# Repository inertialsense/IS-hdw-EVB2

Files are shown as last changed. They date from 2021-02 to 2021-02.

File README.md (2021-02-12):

# EVB-2 Evaluation Board

The Inertial Sense [EVB-2](https://docs.inertialsense.com/user-manual/hardware/EVB2/) is a development board which contains the Inertial Sense µINS, µAHRS, or µIMU module. The EVB-2 builds on the foundation established by the EVB-1, but adds these and other new features:

- 915MHz Xbee radio for RTK (real-time-kinematics)
- Wi-Fi and Bluetooth Low energy (BLE) for remote data viewing and logging operation
- Onboard logging to micro SD card.
- Dual antenna ports for GPS compassing
- Companion Microchip SAME70 processor that serves as a communication bridge between the µINS, µAHRS, or µIMU and all other interfaces.

The EVB-2 PCB assembly design files are provided in Altium Designer format.

------

## LICENSE



Use these Hardware Design files as you wish.  Inertial Sense is not liable for any claim, damages, or other liability resulting from their use.  See the included *LICENSE* file for details.

------

## Revision Info

### r2.1.2

+ Move TIOA1 (TC input) pin from GPIO1 to GPIO9 for measuring encoder velocity on to GPIO9 (multi-tie).  We would not like to have to tie GPIO9 and GPIO3 together offboard the EVB-2 for wheel encoder input.  We share the QDEC and TC input on the same line for angle and velocity measurement.

+ Consider adding a TC input to each of the QDEC channel A lines so all wheel encoder inputs support velocity measurement.
+ Add second CAN transceiver from EVB E70 to H2 and remove CAN jumper.  We can share H2 with uINS and EVB-E70.  Connect transceivers disable line to jumper or EVB disable line.
+ Enlarge fiducials from 0.76mm to 1.0mm on both sides.
+ Fix the I2C line (SDA, SCL) reversal on EVB-2 SAME70.

________________________________________________________________________________

### r2.1.0

+ Dual purpose reset line to reset uINS and MCU using an RC filters.  One resets
  quickly and the other follows after a delay.
+ Consider loading ICE debugger header for SAME70 MCU by default to support
  developers.
+ Expose uINS data ready pin GPIO13 on H7.
+ Fix top layer copper pour for XBee regulator input that connects C20 pin 2 to
  XBee regulator U7 pin 1.
+ Cut trace (disconnect) VUSB from ESD protection for both USB ports.  It's
  causing voltage to appear on FET switches and partially enable.
+ Add EVB version number to PCB
+ Consider switching battery to Seiko MS621T for -40 to 85 C temp range.
+ Add jumper selection of CAN transceiver to uINS and EVB processor for CAN
  support.
+ Consider exposing SAME70 chip erase (PB12) to SMT resistor pads to 3.3V.
+ Fix reversed uINS CAN Rx and Tx lines.  (Double check this).

________________________________________________________________________________

### r2.0.1

+ Add inverted bold labels for I/O headers.
+ Reverse the H1 power pin order so pin 1 is positive and pin 2 ground.
+ Add fiducials to help SMT machine alignment.
+ Invert and increase label size for I/O headers so they are easier to read.
+ Move to new button style
+ Fit shorter U.FL cables
+ Fix error that applied H1 voltage to the USB port in the power schematic
+ Remove or fix XBee USB power FET logic (Q3).
+ Remove R51 and connect with trace.
+ Fix RX line of XOR gate.
+ Add version label.
+ Update manufacturing docs for new U.FL cables (current cables are good)
+ Jumper to G1_SDA and G2_SCL to CAN transceiver to support future generation
  of uINS which will have new processor with CAN stack. 
+ Consider consolidating the power input FET arrays
+ Move INS reset from common reset to MCU pin.
+ Move voltage sensing circuit to analog capable pin of MCU instead of on INS.
+ Connect QDEC2 and QDEC4 lines to H8 so we can support 3 quadrature encoders.
+ Move to 0.0033uF caps on SS/TR lines on voltage regulators to bring rise time
  into spec.

------

(c) 2014-2019 Inertial Sense, Inc.

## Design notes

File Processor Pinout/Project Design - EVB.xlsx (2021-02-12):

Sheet: E70 Pinout
Primary Signal | LFBGA 144 Ball | Power Rail | I/O Type | Dir | Alternate | Dir | PIO Peripheral A | Dir | PIO Peripheral B | Dir | PIO Peripheral C | Dir | PIO Peripheral D | Dir | Reset State | EVB Connection | EVB Pin | Multi Tie |  | Unassigned Connections | Pin
PA0 | C11 | VDDIO | GPIO_AD | I/O | WKUP0(1) | I | PWMC0_PWMH0 | O | TIOA0 (QDEC0 A) | I/O | A17/BA1 | O | I2SC0_MCK | – | PIO,I,PU,ST | GPIO3 | QDEC0 A | Yes
PA1 | D12 | VDDIO | GPIO_AD | I/O | WKUP1(1) | I | PWMC0_PWML0 | O | TIOB0 (QDEC0 B) | I/O | A18 | O | I2SC0_CK | – | PIO,I,PU,ST | GPIO4 | QDEC0 B | Yes
PA2 | E12 | VDDIO | GPIO | I/O | WKUP2(1) | I | PWMC0_PWMH1 | O | – | – | DATRG | I | – | – | PIO,I,PU,ST
PA3 | F12 | VDDIO | GPIO_AD | I/O | PIODC0(2) | I | TWD0 | I/O | LONCOL1 | I | PCK2 | O | – | – | PIO,I,PU,ST | uINS - I2C | SDA
PA4 | K12 | VDDIO | GPIO | I/O | WKUP3/PIODC1(3) | I | TWCK0 | O | TCLK0 | I | UTXD1 | O | – | – | PIO,I,PU,ST | uINS - I2C | SCL
PA5 | M11 | VDDIO | GPIO_AD | I/O | WKUP4/PIODC2(3) | I | PWMC1_PWML3 | O | ISI_D4 | I | URXD1 | I | – | – | PIO,I,PU,ST | uINS - Ser0 | Tx (cross)
PA6 | B9 | VDDIO | GPIO_AD | I/O | – | – | – | – | PCK0 | O | UTXD1 | O | – | – | PIO,I,PU,ST | uINS - Ser0 | Rx (cross)
PA7 | L2 | VDDIO | CLOCK | I/O | XIN32(4) | I | – | – | PWMC0_PWMH3 | O | – | – | – | – | PIO,HiZ | Xin32
PA8 | M2 | VDDIO | CLOCK | I/O | XOUT32(4) | O | PWMC1_PWMH3 | O | AFE0_ADTRG | I | – | – | – | – | PIO,HiZ | Xout32
PA9 | M12 | VDDIO | GPIO_AD | I/O | WKUP6/PIODC3(3) | I | URXD0 | I | ISI_D3 | I | PWMC0_PWMFI0 | I | – | – | PIO,I,PU,ST | uINS - Ser1, SPI | Tx (cross) | Yes
PA10 | L9 | VDDIO | GPIO_AD | I/O | PIODC4(2) | I | UTXD0 | O | PWMC0_PWMEXTRG0 | I | RD | I | – | – | PIO,I,PU,ST | uINS - Ser1, SPI | Rx (cross) | Yes
PA11 | J9 | VDDIO | GPIO_AD | I/O | WKUP7/PIODC5(3) | I | QCS | O | PWMC0_PWMH0 | O | PWMC1_PWML0 | O | – | – | PIO,I,PU,ST | LED - Log | Red
PA12 | L10 | VDDIO | GPIO_AD | I/O | PIODC6(2) | I | QIO1 | I/O | PWMC0_PWMH1 | O | PWMC1_PWMH0 | O | – | – | PIO,I,PU,ST | LED - Log | Blue
PA13 | M3 | VDDIO | GPIO_AD | I/O | PIODC7(2) | I | QIO0 | I/O | PWMC0_PWMH2 | O | PWMC1_PWML1 | O | – | – | PIO,I,PU,ST | LED - Config | Green
PA14 | K6 | VDDIO | GPIO_CLK | I/O | WKUP8/PIODCEN1(3) | I | QSCK | O | PWMC0_PWMH3 | O | PWMC1_PWMH1 | O | – | – | PIO,I,PU,ST
PA15 | L5 | VDDIO | GPIO_AD | I/O | – | – | D14 | I/O | TIOA1 | I/O | PWMC0_PWML3 | O | I2SC0_WS | – | PIO,I,PU,ST | GPIO9 |  | Yes |  |  |  | Multi-Ties
PA16 | K5 | VDDIO | GPIO_AD | I/O | – | – | D15 | I/O | TIOB1 (QDEC0 Idx) | I/O | PWMC0_PWML2 | O | I2SC0_DI | – | PIO,I,PU,ST | GPIO2 | QDEC0 Idx | Yes |  |  |  | EVB Connection | EVB Pins | Option1 | Pin | Option2 | Pin | Option3 | Pin | Option4 | Pin | Option5 | Pin
PA17 | J1 | VDDIO | GPIO_AD | I/O | AFE0_AD6(5) | I | QIO2 | I/O | PCK1 | O | PWMC0_PWMH3 | O | – | – | PIO,I,PU,ST | M-USB ID |  |  |  |  |  | GPIO1 | PB4 | TXD1 (MISO) | PB4
PA18 | H2 | VDDIO | GPIO_AD | I/O | AFE0_AD7(5) | I | PWMC1_PWMEXTRG1 | I | PCK2 | O | A14 | O | – | – | PIO,I,PU,ST | SP330-SLEW |  |  |  |  |  | GPIO2 | PA16, PA21 | RXD1 (MOSI) | PA21 | TIOB1 (QDEC0 Idx) | PA16 | AFE0_AD1 | PA21 | PWMC0_PWML2 | PA16
PA19 | H1 | VDDIO | GPIO_AD | I/O | AFE0_AD8/WKUP9(6) | I | – | – | PWMC0_PWML0 | O | A15 | O | I2SC1_MCK | – | PIO,I,PU,ST | SP330-SHDN |  |  |  |  |  | GPIO3 | PA0, PA23, PE3 | SCK1 (SCLK) | PA23 | TIOA0 (QDEC0 A) | PA0 | AFE1_AD10(5) |  | PWMC0_PWMH0 | PA0 | TIOA10 | PE3
PA20 | H3 | VDDIO | GPIO_AD | I/O | AFE0_AD9/WKUP10(6) | I | – | – | PWMC0_PWML1 | O | A16/BA0 | O | I2SC1_CK | – | PIO,I,PU,ST | SP330-RXEN |  |  |  |  |  | GPIO4 | PA1, PA24, | RTS1 (CS) | PA24 | TIOB0 (QDEC0 B) | PA1 |  |  | PWMC0_PWML0 | PA1
PA21 | K2 | VDDIO | GPIO_AD | I/O | AFE0_AD1/PIODCEN2(8) | I | RXD1 | I | PCK1 | O | PWMC1_PWMFI0 | I | – | – | PIO,I,PU,ST | GPIO2 | Rx | Yes |  |  |  | GPIO5 | PB13, PC5, PC29 | DAC0 | PB13 | TIOA6 (QDEC2 A) | PC5 | AFE1_AD4 | PC29 | PWMC0_PWML2 | PB13 | TIOA5 | PC29
PA22 | K3 | VDDIO | GPIO_AD | I/O | PIODCCLK(2) | I | RK | I/O | PWMC0_PWMEXTRG1 | I | NCS2 | O | – | – | PIO,I,PU,ST |  |  |  |  |  |  | GPIO6 | PC6, PD0 | DAC1 | PD0 | TIOB6 (QDEC2 B) | PC6 |  |  | PWMC1_PWML0 | PD0
PA23 | L4 | VDDIO | GPIO_AD | I/O | – | – | SCK1 | I/O | PWMC0_PWMH0 | O | A19 | O | PWMC1_PWML2 | O | PIO,I,PU,ST | GPIO3 | SCK | Yes |  |  |  | GPIO7 | PC9 |  |  | TIOB7 (QDEC2 Idx) | PC9
PA24 | L7 | VDDIO | GPIO_AD | I/O | – | – | RTS1 | O | PWMC0_PWMH1 | O | A20 | O | ISI_PCK | I | PIO,I,PU,ST | GPIO4 | CS | Yes |  |  |  | GPIO8 | PD27, PE4 |  |  | TIOB10 (QDEC3 Idx) | PE4 | AFE0_AD4 (PC29) | PE4 | PWMC0_PWML3 | PD27
PA25 | K8 | VDDIO | GPIO_AD | I/O | – | – | CTS1 | I | PWMC0_PWMH2 | O | A23 | O | MCCK | O | PIO,I,PU,ST | SD Card | CLK |  |  |  |  | GPIO9 | PA15, PC13, PE0 |  |  | TIOA9 (QDEC3 A) | PE0 | AFE1_AD1/AFE1_AD10 | PC13/PE0 | PWMC0_PWMH3 | PC13 | TIOA1 | PA15
PA26 | J8 | VDDIO | GPIO_AD | I/O | – | – | DCD1 | I | TIOA2 | O | MCDA2 | I/O | PWMC1_PWMFI1 | I | PIO,I,PU,ST | SD Card | D2 |  |  |  |  | GPIO10 | PC15, PE1 |  |  | TIOB9 (QDEC3 B) | PE1 | AFE1_AD2 | PC15 | PWMC0_PWML3 | PC15
PA27 | J10 | VDDIO | GPIO_AD | I/O | – | – | DTR1 | O | TIOB2 | I/O | MCDA3 | I/O | ISI_D7 | I | PIO,I,PU,ST | SD Card | D3 |  |  |  |  | uINS - Ser1, SPI | Tx (cross) | URXD0 |  | SPI0_MISO
PA28 | C9 | VDDIO | GPIO_AD | I/O | – | – | DSR1 | I | TCLK1 | I | MCCDA | I/O | PWMC1_PWMFI2 | I | PIO,I,PU,ST | SD Card | CMD |  |  |  |  | uINS - Ser1, SPI | Rx (cross) | UTXD0 |  | SPI0_MOSI
PA29 | A6 | VDDIO | GPIO_AD | I/O | – | – | RI1 | I | TCLK2 | I | – | – | – | – | PIO,I,PU,ST | Xbee - UART | RST
PA30 | A10 | VDDIO | GPIO_AD | I/O | WKUP11(1) | I | PWMC0_PWML2 | O | PWMC1_PWMEXTRG0 | I | MCDA0 | I/O | I2SC0_DO | – | PIO,I,PU,ST | SD Card | D0
PA31 | C8 | VDDIO | GPIO_AD | I/O | – | – | SPI0_NPCS1 | I/O | PCK2 | O | MCDA1 | I/O | PWMC1_PWMH2 | O | PIO,I,PU,ST | SD Card | D1
PB0 | H4 | VDDIO | GPIO_AD | I/O | AFE0_AD10/RTCOUT0(7) | I | PWMC0_PWMH0 | O | – | – | RXD0 | I | TF | I/O | PIO,I,PU,ST | Xbee - UART | Tx (cross)
PB1 | G3 | VDDIO | GPIO_AD | I/O | AFE1_AD0/RTCOUT1(7) | I | PWMC0_PWMH1 | O | GTSUCOMP | O | TXD0 | I/O | TK | I/O | PIO,I,PU,ST | Xbee - UART | Rx (cross)
PB2 | J2 | VDDIO | GPIO_AD | I/O | AFE0_AD5(5) | I | CANTX0 | O | – | – | CTS0 | I | SPI0_NPCS0 | I/O | PIO,I,PU,ST | Xbee - UART | CTS (no cross)
PB3 | J3 | VDDIO | GPIO_AD | I/O | AFE0_AD2/WKUP12(6) | I | CANRX0 | I | PCK2 | O | RTS0 | O | ISI_D2 | I | PIO,I,PU,ST | Xbee - UART | RTS (no cross)
PB4 | A12 | VDDIO | GPIO_AD | I/O | TDI(9) | I | TWD1 | I/O | PWMC0_PWMH2 | O | – | – | TXD1 | I/O | PIO,I,PD,ST | GPIO1 | Tx
PB5 | C10 | VDDIO | GPIO_AD | I/O | TDO/TRACESWO/WKUP13(9) | O | TWCK1 | O | PWMC0_PWML0 | O | – | – | TD | O | O,PU | JTAG | SWO/TDO
PB6 | J11 | VDDIO | GPIO_AD | I/O | SWDIO/TMS(9) | I | – | – | – | – | – | – | – | – | PIO,I,ST | JTAG | SWDIO/TMS
PB7 | F9 | VDDIO | GPIO_AD | I/O | SWCLK/TCK(9) | I | – | – | – | – | – | – | – | – | PIO,I,ST | JTAG | SWCLK/TCK
PB8 | A3 | VDDIO | GPIO_AD | I/O | XOUT(10) | O | – | – | – | – | – | – | – | – | PIO,HiZ | Xout
PB9 | A2 | VDDIO | GPIO_AD | I/O | XIN(10) | I | – | – | – | – | – | – | – | – | PIO,HiZ | Xin
PB12 | G12 | VDDIO | GPIO_AD | I/O | ERASE(9) | I | PWMC0_PWML1 | O | GTSUCOMP | O | – | – | PCK0 | O | PIO,I,PD,ST
PB13 | B2 | VDDIO | GPIO_AD | I/O | DAC0(11) | O | PWMC0_PWML2 | O | PCK0 | O | SCK0 | I/O | – | – | PIO,I,PU,ST | GPIO5 | DAC | Yes
PC0 | E4 | VDDIO | GPIO_AD | I/O | AFE1_AD9(5) | I | D0 | I/O | PWMC0_PWML0 | O | – | – | – | – | PIO,I,PU,ST | Hardware Detect 0
PC1 | J4 | VDDIO | GPIO_AD | I/O | – | – | D1 | I/O | PWMC0_PWML1 | O | – | – | – | – | PIO,I,PU,ST | Hardware Detect 1
PC2 | K4 | VDDIO | GPIO_AD | I/O | – | – | D2 | I/O | PWMC0_PWML2 | O | – | – | – | – | PIO,I,PU,ST | Hardware Detect 2
PC3 | L3 | VDDIO | GPIO_AD | I/O | – | – | D3 | I/O | PWMC0_PWML3 | O | – | – | – | – | PIO,I,PU,ST | Config Button
PC4 | J5 | VDDIO | GPIO_AD | I/O | – | – | D4 | I/O | – | – | – | – | – | – | PIO,I,PU,ST
PC5 | L8 | VDDIO | GPIO_AD | I/O | – | – | D5 | I/O | TIOA6 (QDEC2 A) | I/O | – | – | – | – | PIO,I,PU,ST | GPIO5 | QDEC2 A | Yes
PC6 | K7 | VDDIO | GPIO_AD | I/O | – | – | D6 | I/O | TIOB6 (QDEC2 B) | I/O | – | – | – | – | PIO,I,PU,ST | GPIO6 | QDEC2 B
PC7 | M4 | VDDIO | GPIO_AD | I/O | – | – | D7 | I/O | TCLK6 | I | – | – | – | – | PIO,I,PU,ST | Log Button
PC8 | J12 | VDDIO | GPIO_AD | I/O | – | – | NWR0/NWE | O | TIOA7 | I/O | – | – | – | – | PIO,I,PU,ST | LED INS Rx
PC9 | G11 | VDDIO | GPIO_AD | I/O | – | – | NANDOE | O | TIOB7 (QDEC2 Idx) | I/O | – | – | – | – | PIO,I,PU,ST | GPIO7 | QDEC2 Idx
PC10 | F10 | VDDIO | GPIO_AD | I/O | – | – | NANDWE | O | TCLK7 | I | – | – | – | – | PIO,I,PU,ST | LED Bee Rx
PC11 | F11 | VDDIO | GPIO_AD | I/O | – | – | NRD | O | TIOA8 | I/O | – | – | – | – | PIO,I,PU,ST | LED Bee Tx
PC12 | F4 | VDDIO | GPIO_AD | I/O | AFE1_AD3(5) | I | NCS3 | O | TIOB8 | I/O | CANRX1 | I | – | – | PIO,I,PU,ST | CAN - Xcvr | Rx |  | Cross in transciever
PC13 | G2 | VDDIO | GPIO_AD | I/O | AFE1_AD1(5) | I | NWAIT | I | PWMC0_PWMH3 | O | SDA10 | O | – | – | PIO,I,PU,ST | GPIO9 |  | Yes
PC14 | E10 | VDDIO | GPIO_AD | I/O | – | – | NCS0 | O | TCLK8 | I | CANTX1 | O | – | – | PIO,I,PU,ST | CAN - Xcvr | Tx |  | Cross in transciever
PC15 | G1 | VDDIO | GPIO_AD | I/O | AFE1_AD2(5) | I | NCS1/SDCS | O | PWMC0_PWML3 | O | – | – | – | – | PIO,I,PU,ST | GPIO10 |  | Yes
PC16 | D11 | VDDIO | GPIO_AD | I/O | – | – | A21/NANDALE | O | – | – | – | – | – | – | PIO,I,PU,ST | SD Card | Detect
PC17 | B12 | VDDIO | GPIO_AD | I/O | – | – | A22/NANDCLE | O | – | – | – | – | – | – | PIO,I,PU,ST | WINC LED Rx
PC18 | B10 | VDDIO | GPIO_AD | I/O | – | – | A0/NBS0 | O | PWMC0_PWML1 | O | – | – | – | – | PIO,I,PU,ST | SP330 Duplex
PC19 | D8 | VDDIO | GPIO_AD | I/O | – | – | A1 | O | PWMC0_PWMH2 | O | – | – | – | – | PIO,I,PU,ST
PC20 | A9 | VDDIO | GPIO_AD | I/O | – | – | A2 | O | PWMC0_PWML2 | O | – | – | – | – | PIO,I,PU,ST | uINS SPI Enable
PC21 | A7 | VDDIO | GPIO_AD | I/O | – | – | A3 | O | PWMC0_PWMH3 | O | – | – | – | – | PIO,I,PU,ST | ATWINC - WiFi | RST
PC22 | C7 | VDDIO | GPIO_AD | I/O | – | – | A4 | O | PWMC0_PWML3 | O | – | – | – | – | PIO,I,PU,ST | ATWINC - WiFi | CHIP-EN
PC23 | C6 | VDDIO | GPIO_AD | I/O | – | – | A5 | O | TIOA3 (QDEC1 A) | I/O | – | – | – | – | PIO,I,PU,ST | ATWINC - WiFi | WiFi-IRQN
PC24 | B6 | VDDIO | GPIO_AD | I/O | – | – | A6 | O | TIOB3 (QDEC1 B) | I/O | SPI1_SPCK | O | – | – | PIO,I,PU,ST | ATWINC - WiFi | SCLK
PC25 | C5 | VDDIO | GPIO_AD | I/O | – | – | A7 | O | TCLK3 | I | SPI1_NPCS0 | I/O | – | – | PIO,I,PU,ST | ATWINC - WiFi | CS
PC26 | F2 | VDDIO | GPIO_AD | I/O | AFE1_AD7(5) | I | A8 | O | TIOA4 | I/O | SPI1_MISO | I | – | – | PIO,I,PU,ST | ATWINC - WiFi | MISO
PC27 | E2 | VDDIO | GPIO_AD | I/O | AFE1_AD8(5) | I | A9 | O | TIOB4 (QDEC1 Idx) | I/O | SPI1_MOSI | O | – | – | PIO,I,PU,ST | ATWINC - WiFi | MOSI
PC28 | L12 | VDDIO | GPIO_AD | I/O | – | – | A10 | O | TCLK4 | I | SPI1_NPCS1 | I/O | – | – | PIO,I,PU,ST | LED INS Tx
PC29 | F3 | VDDIO | GPIO_AD | I/O | AFE1_AD4(5) | I | A11 | O | TIOA5 | I/O | SPI1_NPCS2 | O | – | – | PIO,I,PU,ST | GPIO5 | TC, AD | Yes |  | Can be removed if needed
PC30 | F1 | VDDIO | GPIO_AD | I/O | AFE1_AD5(5) | I | A12 | O | TIOB5 | I/O | SPI1_NPCS3 | O | – | – | PIO,I,PU,ST |  |  |  |  | GPS Timepulse
PC31 | E1 | VDDIO | GPIO_AD | I/O | AFE1_AD6(5) | I | A13 | O | TCLK5 | I | – | – | – | – | PIO,I,PU,ST
PD0 | D4 | VDDIO | GPIO_AD | I/O | DAC1(11) | I | GTXCK | I | PWMC1_PWML0 | O | SPI1_NPCS1 | I/O | DCD0 | I | PIO,I,PU,ST | GPIO6 | DAC | Yes
PD1 | B5 | VDDIO | GPIO_AD | I/O | – | – | GTXEN | O | PWMC1_PWMH0 | O | SPI1_NPCS2 | I/O | DTR0 | O | PIO,I,PU,ST | Xbee - UART | DTR
PD2 | A5 | VDDIO | GPIO_AD | I/O | – | – | GTX0 | O | PWMC1_PWML1 | O | SPI1_NPCS3 | I/O | DSR0 | I | PIO,I,PU,ST | INS Data Ready
PD3 | B7 | VDDIO | GPIO_AD | I/O | – | – | GTX1 | O | PWMC1_PWMH1 | O | UTXD4 | O | RI0 | I | PIO,I,PU,ST | LED - Config | Blue
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

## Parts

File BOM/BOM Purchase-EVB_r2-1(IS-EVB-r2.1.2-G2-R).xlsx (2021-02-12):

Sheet: BOM
BOM | IS-EVB-r2.1.2-G2-R |  |  | C O N F I D E N T I A L / P R O R I E T A R Y
 | Evaluation Board |  |  |  |  | InertialSense
PCB Part Number: | IS-EVB-r2.1.2 |  |  | Production Qty: | 100 | 3000 S Sierra Vista Way Suite 2
 |  |  |  | Total Cost: | $18316.07 | Provo, UT 84606
Report Date: | 1/22/2021 | 10:26 AM |  |  |  | 801-610-6359
Print Date: | 2021-01-22 | 10:27:03 |  |  |  | info@inertialsense.com
Fitted | Quantity | Description | Designator | Manufacturer Part Number | Manufacturer | Supplier Part Number 1 | Supplier 1 | Supplier Unit Price 1 | Supplier Subtotal 1
Fitted | 1 | BATTERY LITH 3V RECHARGE SMD | BAT1 | MS621T-FL11E | Seiko | 728-1080-ND | Digi-Key | $1.79 | $179.14
Fitted | 8 | CAP CER 10UF 35V X5R 0805 | C1, C12, C20, C29, C52, C54, C55, C56 | C2012X5R1V106K085AC | TDK | 445-14417-6-ND | Digi-Key | $0.16 | $131.87
Fitted | 19 | CAP CER .10UF 50V X7R 10% 0402 | C2_I, C2_M, C5, C9, C13, C14, C16, C22, C23, C24, C25, C26, C27, C28, C30, C32, C41, C51, C57 | C1005X7R1H104K | TDK Corporation | 445-5932-1-ND | Digi-Key | $0.02 | $40.81
Fitted | 1 | CAP CER 0.22UF 16V X7R 0402 | C3 | GRM155R71C224KA12D | Murata | 490-5418-6-ND | Digi-Key | $0.04 | $3.78
Fitted | 1 | CAP CER 10PF 50V C0G 0402 | C4 | C1005C0G1H100D050BA | TDK | 445-1235-6-ND | Digi-Key | $0.03 | $2.91
Fitted | 2 | CAP CER 15PF 16V C0G/NP0 0402 | C6, C7 | C0402C150J4GACTU | KEMET | 399-8947-6-ND | Digi-Key | $0.01 | $1.94
Fitted | 17 | CAP CER 0.1UF 25V X5R 0201 | C8, C11, C19, C36, C37, C38, C39, C40, C42, C43, C44, C45, C46, C47, C48, C49, C50 | GRM033R6YA104KE14D | Murata | 490-10430-1-ND | Digi-Key | $0.01 | $21.59
Fitted | 3 | CAP CER 22UF 10V X5R 1206 | C10, C18, C33 | CL31A226KPHNNNE | Samsung | 1276-1287-6-ND | Digi-Key | $0.17 | $50.49
Fitted | 2 | CAP CER 0.0033UF 50V X7R 0402 | C15, C21 | CL05B332JB5NNNC | Samsung | 1276-1548-6-ND | Digi-Key | $0.01 | $2.68
Fitted | 2 | CAP CER 1UF 25V X7R 0603 | C17, C31 | CL10B105KA8NNNC | Samsung | 1276-1184-6-ND | Digi-Key | $0.02 | $4.02
Fitted | 1 | CAP CER 0.047UF 16V Y5V 0402 | C34 | CC0402ZRY5V7BB473 | Yageo | 311-1046-6-ND | Digi-Key | $0.01 | $1.12
Fitted | 2 | CAP CER 2.2UF 6.3V X5R 0603 | C35, C53 | CL10A225KQ8NNWC | Samsung | 1276-1886-1-ND | Digi-Key | $0.03 | $6.34
Fitted | 5 | LED RGB DIFFUSED 0404 SMD | D1, D2, D3, D4, D5 | SMLP34RGB2W3 | Rohm Semiconductor | SMLP34RGB2W3TR-ND | Digi-Key | $0.36 | $1787.95
Fitted | 2 | DIODE SCHOTTKY 30V 2A 0603 | D6, D7 | VSKY20301608-G4-08 | Vishay | VSKY20301608-G4-08GICT-ND | Digi-Key
Fitted | 1 | CONN HEADER PH SIDE 2POS 2MM SMD | H1 | S2B-PH-SM4-TB(LF)(SN) | JST | 455-1749-1-ND | Digi-Key | $0.38 | $38.13
Fitted | 1 | CONN HEADER GH SIDE 4POS 1.25MM | H2 | SM04B-GHS-TB(LF)(SN)- | JST | 455-1566-1-ND | Digi-Key | $0.31 | $31.42
Fitted | 1 | CONN HEADER GH SIDE 5POS 1.25MM | H3 | SM05B-GHS-TB(LF)(SN) | JST | 455-1567-1-ND | Digi-Key
Fitted | 1 | CONN HEADER GH SIDE 9POS 1.25MM | H4 | SM09B-GHS-TB(LF)(SN) | JST | 455-1571-2-ND | Digi-Key
Fitted | 1 | CONN HEADER 10POS DUAL .05" SMD | H5 | FTSH-105-01-L-DV-K-A-P | Samtec | SAM9440-ND | Digi-Key | $3.32 | $332.00
Fitted | 2 | CONN HEADER GH SIDE 14POS 1.25MM | H7, H8 | SM14B-GHS-TB(LF)(SN) | JST | 455-1576-6-ND | Digi-Key
Fitted | 1 | CONN MICRO SD CARD PUSH-PULL R/A | H9 | 114-00841-68 | Amphenol Commercial | 114-00841-68-6-ND | Digi-Key | $1.09 | $108.57
Fitted | 4 | FIXED IND 1UH 3.3A 40 MOHM | I1, I3, I4, I8 | DFE252012F-1R0M=P2 | Murata | 490-13053-6-ND | Digi-Key | $0.34 | $136.30
Fitted | 1 | FERRITE BEAD 240 OHM 0201 1LN | I2 | MMZ0603S241HT000 | TDK Corporation | 445-172341-1-ND | Digi-Key | $0.06 | $5.50
Fitted | 1 | FIXED IND 10UH 350MA 1.066 OHM | I5 | CBC2016T100M | Taiyo Yuden | 587-1606-1-ND | Digi-Key | $0.14 | $14.40
Fitted | 2 | FERRITE BEAD 470 OHM 0402 | I6, I7 | BK1005HM471-T | Taiyo Yuden | 587-1838-6-ND | Digi-Key | $0.02 | $4.95
Fitted | 2 | CONN USB MICRO B RECPT SMT R/A | J2_I, J2_M | 10118194-0001LF | Amphenol FCI | 609-4618-6-ND | Digi-Key | $0.32 | $63.16
Fitted | 3 | CONN UMC RCPT STR 50 OHM SMD | J3, J4, J8 | 128-0711-201 | Emerson Network Power Connectivity Johnson | J983CT-ND | Digi-Key | $0.49 | $145.80
Fitted | 1 | CONN RPSMA JCK STR 50OHM EDGEMNT | J5 | 132255RP | Amphenol Connex | ACX1425-ND | Digi-Key | $7.10 | $710.40
Fitted | 2 | CONN SMA RCPT STR 50OHM EDGE MNT | J6, J7 | 732511150 | Molex | WM5534-ND | Digi-Key | $2.10 | $420.32
Fitted | 3 | CBL ASSY UMCC PLUG-PLUG 1.969" | J9, J10, J11 | 415-0084-050 | Bel Cinch | J918-ND | Digi-Key
Fitted | 4 | RND STANDOFF M2.5X0.45 STEEL 5MM | MP1, MP2, MP3, MP4 | 9774050951R | Wurth Electronics | 732-7098-1-ND | Digi-Key | $0.74 | $295.60
Fitted | 4 | 4V DRIVE PCH+PCH MOSFET | Q1, Q2, Q5, Q6 | TT8J3TR | Rohm | TT8J3TRCT-ND | Digi-Key | $0.36 | $145.60
Fitted | 11 | RES SMD 100K OHM 1% 1/16W 0402 | R1, R2, R8, R14, R23, R38, R39, R44, R45, R48, R49 | ERJ-2RKF1003X | Panasonic | P100KLDKR-ND | Digi-Key | $0.00398 | $4.38
Fitted | 1 | RES SMD 5.62K OHM 1% 1/10W 0402 | R4 | ERJ-2RKF5621X | Panasonic | P5.62KLDKR-ND | Digi-Key | $0.01 | $0.88
Fitted | 7 | RES 10K OHM 1/16W 1% 0402 SMD | R5, R9, R19, R20, R35, R41, R43 | ERJ-2RKF1002X | Panasonic | P10.0KLDKR-ND | Digi-Key | $0.00398 | $3.98
Fitted | 2 | RES SMD 560K OHM 1% 1/10W 0402 | R6, R12 | ERJ-2RKF5603X | Panasonic | P560KLDKR-ND | Digi-Key | $0.01 | $1.76
Fitted | 2 | RES SMD 150K OHM 1% 1/10W 0402 | R7, R13 | ERJ-2RKF1503X | Panasonic | P150KLDKR-ND | Digi-Key | $0.01 | $1.78
Fitted | 12 | RES SMD 470 OHM 5% 1/16W 0402 | R10, R28, R29, R30, R31, R32, R36, R40, R42, R46, R55, R56 | CRCW0402470RJNED | Vishay Dale | 541-470JDKR-ND | Digi-Key | $0.01 | $6.13
Fitted | 1 | RES SMD 120 OHM 5% 1/4W 0603 | R11 | ESR03EZPJ121 | Rohm | RHM120DDKR-ND | Digi-Key | $0.03 | $2.75
Fitted | 4 | RES 470 OHM 1/16W 1% 0402 SMD | R21, R24, R33, R34 | CRCW0402470RFKED | Vishay Dale | 541-470LCT-ND | Digi-Key | $0.01 | $5.32
Fitted | 1 | RES SMD 1M OHM 5% 1/10W 0402 | R22 | ERJ-2GEJ105X | Panasonic | P1.0MJDKR-ND | Digi-Key | $0.01 | $0.77
Fitted | 1 | RES 1.00K OHM 1/16W 1% 0402 SMD | R26 | RC0402FR-071KL | Yageo | 311-1.00KLRCT-ND | Digi-Key | $0.01 | $0.58
Fitted | 1 | RES SMD 0 OHM JUMPER 1/16W 0402 | R51 | RC0402JR-070RL | Yageo | 311-0.0JRDKR-ND | Digi-Key | $0.0047 | $0.47
Fitted | 1 | RES SMD 1M OHM 1% 1/16W 0402 | R54 | RC0402FR-071ML | Yageo | 311-1.00MLRCT-ND | Digi-Key | $0.01 | $0.58
Fitted | 3 | SWITCH TACTILE SPST-NO 0.05A 16V | S1, S2, S3 | PTS810SJK250SMTRLFS | ITT C&K | CKN10503DKR-ND | Digi-Key | $0.25 | $73.60
Fitted | 2 | TVS DIODE 5.5V SOT5 | U1_I, U1_M | TPD3E001DRLR | Texas Instruments | 296-21885-1-ND | Digi-Key | $0.29 | $58.24
Fitted | 1 | IC GATE XOR 2CH 2-INP US8 | U2 | SN74LVC2G86DCUR | Texas Instruments | 595-SN74LVC2G86DCUR | Mouser | $0.36 | $36.40
Fitted | 1 | IC MCU 32BIT 1MB FLASH 144LFBGA | U3 | ATSAME70Q20B-CNT | Microchip | ATSAME70Q20B-CNTDKR-ND | Digi-Key | $16.53 | $1653.00
Fitted | 2 | IC REG BUCK ADJ 3.5A 11VQFN | U4, U7 | TPS62135RGXR | Texas Instruments | 296-47242-6-ND | Digi-Key | $1.55 | $309.52
Fitted | 2 | IC TXRX CAN 3.3V SOT23-8 | U5, U13 | TCAN334DCNR | Texas Instruments | 296-47830-1-ND | Digi-Key | $1.81 | $362.94
Fitted | 1 | IC TXRX RS232/485 24TSSOP | U6 | SP330EEY-L | Exar | 1016-1977-ND | Digi-Key | $2.87 | $286.89
Fitted | 1 | WIFI/BLE MODULE | U8 | ATWINC3400-MR210UA122 | Microchip | ATWINC3400-MR210UA122-ND | Digi-Key | $10.20 | $1020.00
Fitted | 1 | Inertial Sense uINS | U9 | IS-uINS-3.2-G2 | Inertial Sense | IS-uINS-3.2-G2 | Inertial Sense
Fitted | 1 | XBEE PRO MOD TXRX ISM 915MHZ UFL | U10 | XBP9X-DMUS-001 | Digi International | 602-1890-ND | Digi-Key | $86.25 | $8625.00
Fitted | 1 | VARISTOR 0402 | V1 | CG0402MLC-12LG | Bourns | CG0402MLC-12LGCT-ND | Digi-Key | $0.23 | $22.75
Fitted | 1 | CRYSTAL 32.7680KHZ 9PF SMD | Y1 | ABS06-32.768KHZ-9-1-T | Abracon LLC | 535-10247-1-ND | Digi-Key | $1.42 | $141.75
Fitted | 1 | OSC XO 12.000MHZ HCMOS SMD | Y2 | ECS-2520S33-120-FN-TR | ECS Inc. | XC2194TR-ND | Digi-Key | $0.93 | $929.25
Fitted | 1 | OSC MEMS 32.768KHZ LVCMOS SMD | Y3 | SIT1533AI-H4-DCC-32.768E | SiTime | 1473-1239-1-ND | Digi-Key | $0.81 | $80.56
Not Fitted | 0 | CONN HEADER 10POS DUAL .05" SMD | H6 | FTSH-105-01-L-DV-K-A-P | Samtec | SAM9440-ND | Digi-Key
Not Fitted | 0 | RES SMD 0 OHM JUMPER 1/10W 0603 | R3 | RC0603JR-070RL | Yageo | 311-0.0GRDKR-ND | Digi-Key
Not Fitted | 0 | RES SMD 0 OHM JUMPER 1/16W 0402 | R17, R18, R27, R37 | RC0402JR-070RL | Yageo | 311-0.0JRDKR-ND | Digi-Key
Not Fitted | 0 | RES 1.00K OHM 1/16W 1% 0402 SMD | R25, R53
Not Fitted | 0 | RES 1.00K OHM 1/16W 1% 0402 SMD | R47 | RC0402FR-071KL | Yageo | 311-1.00KLRCT-ND | Digi-Key
Not Fitted | 0 | IC FLASH 128M SPI 133MHZ 8SOIC | U11 | W25Q128JVSIQTR | Winbond | W25Q128JVSIQCT-ND | Digi-Key
Not Fitted | 0 | IC FLASH 1G/2G SPI 8UPDFN | U12 | MT29F2G01ABAGDWB-IT:GTR | Micron Technology | 557-1664-6-ND | Digi-Key

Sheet: Digikey Order
Production Qty: | 100
 |  | Quantity | Total | Supplier Part Number 1 | Designator
 |  | 1 | 100 | 728-1080-ND | BAT1
 |  | 8 | 800 | 445-14417-6-ND | C1, C12, C20, C29, C52, C54, C55, C56

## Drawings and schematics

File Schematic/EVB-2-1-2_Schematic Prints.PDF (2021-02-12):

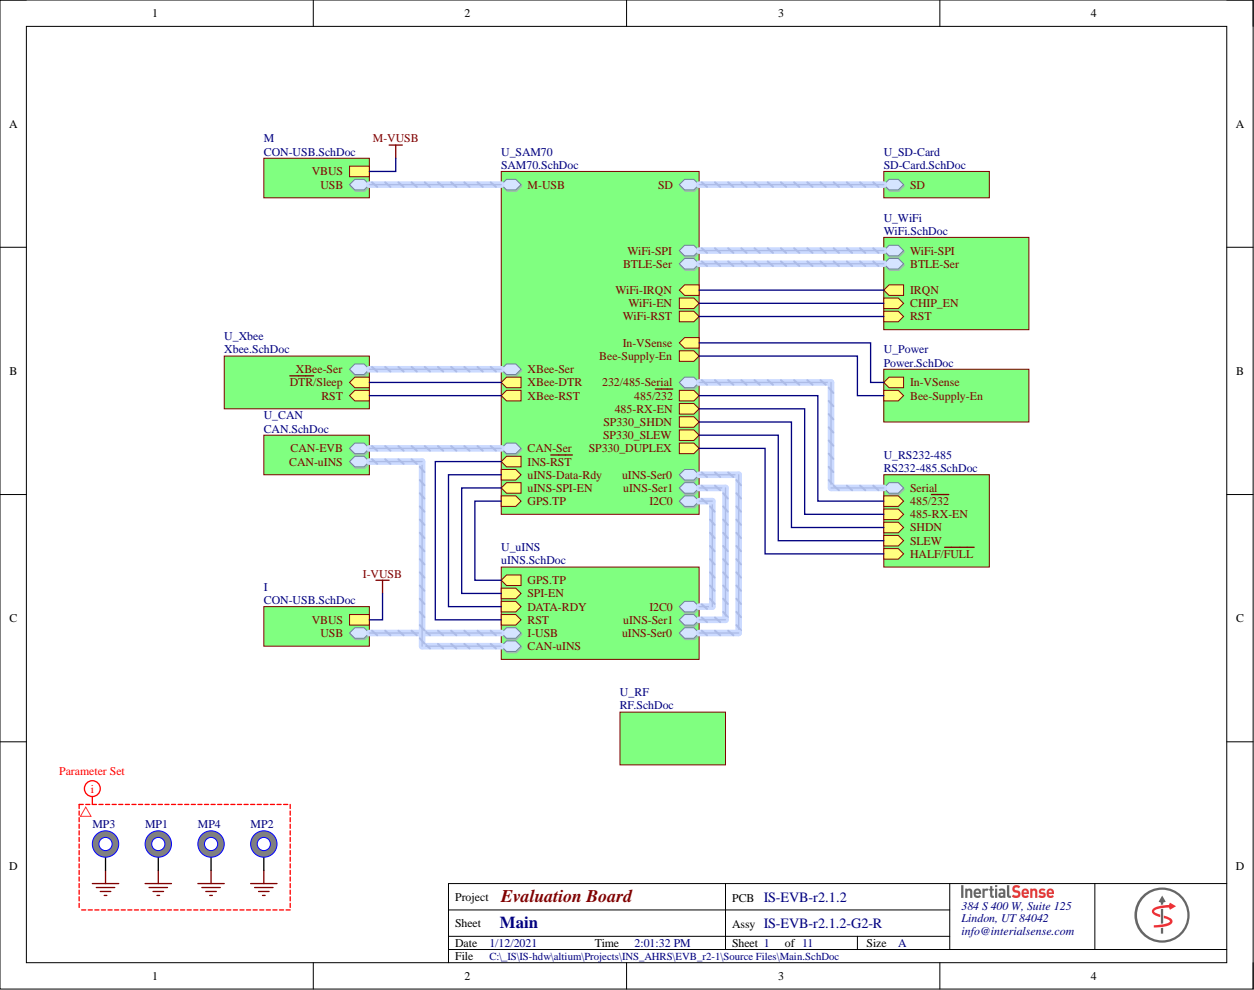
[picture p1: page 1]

U_SD-Card SD-Card.SchDoc

WiFi-IRQN WiFi-EN WiFi-RST

U_Power
Power.SchDoc
Bee-Supply-En In-VSense

IS-EVB-r2.1.2
PCB
IS-EVB-r2.1.2-
Assy
urce Files\Main.SchDo

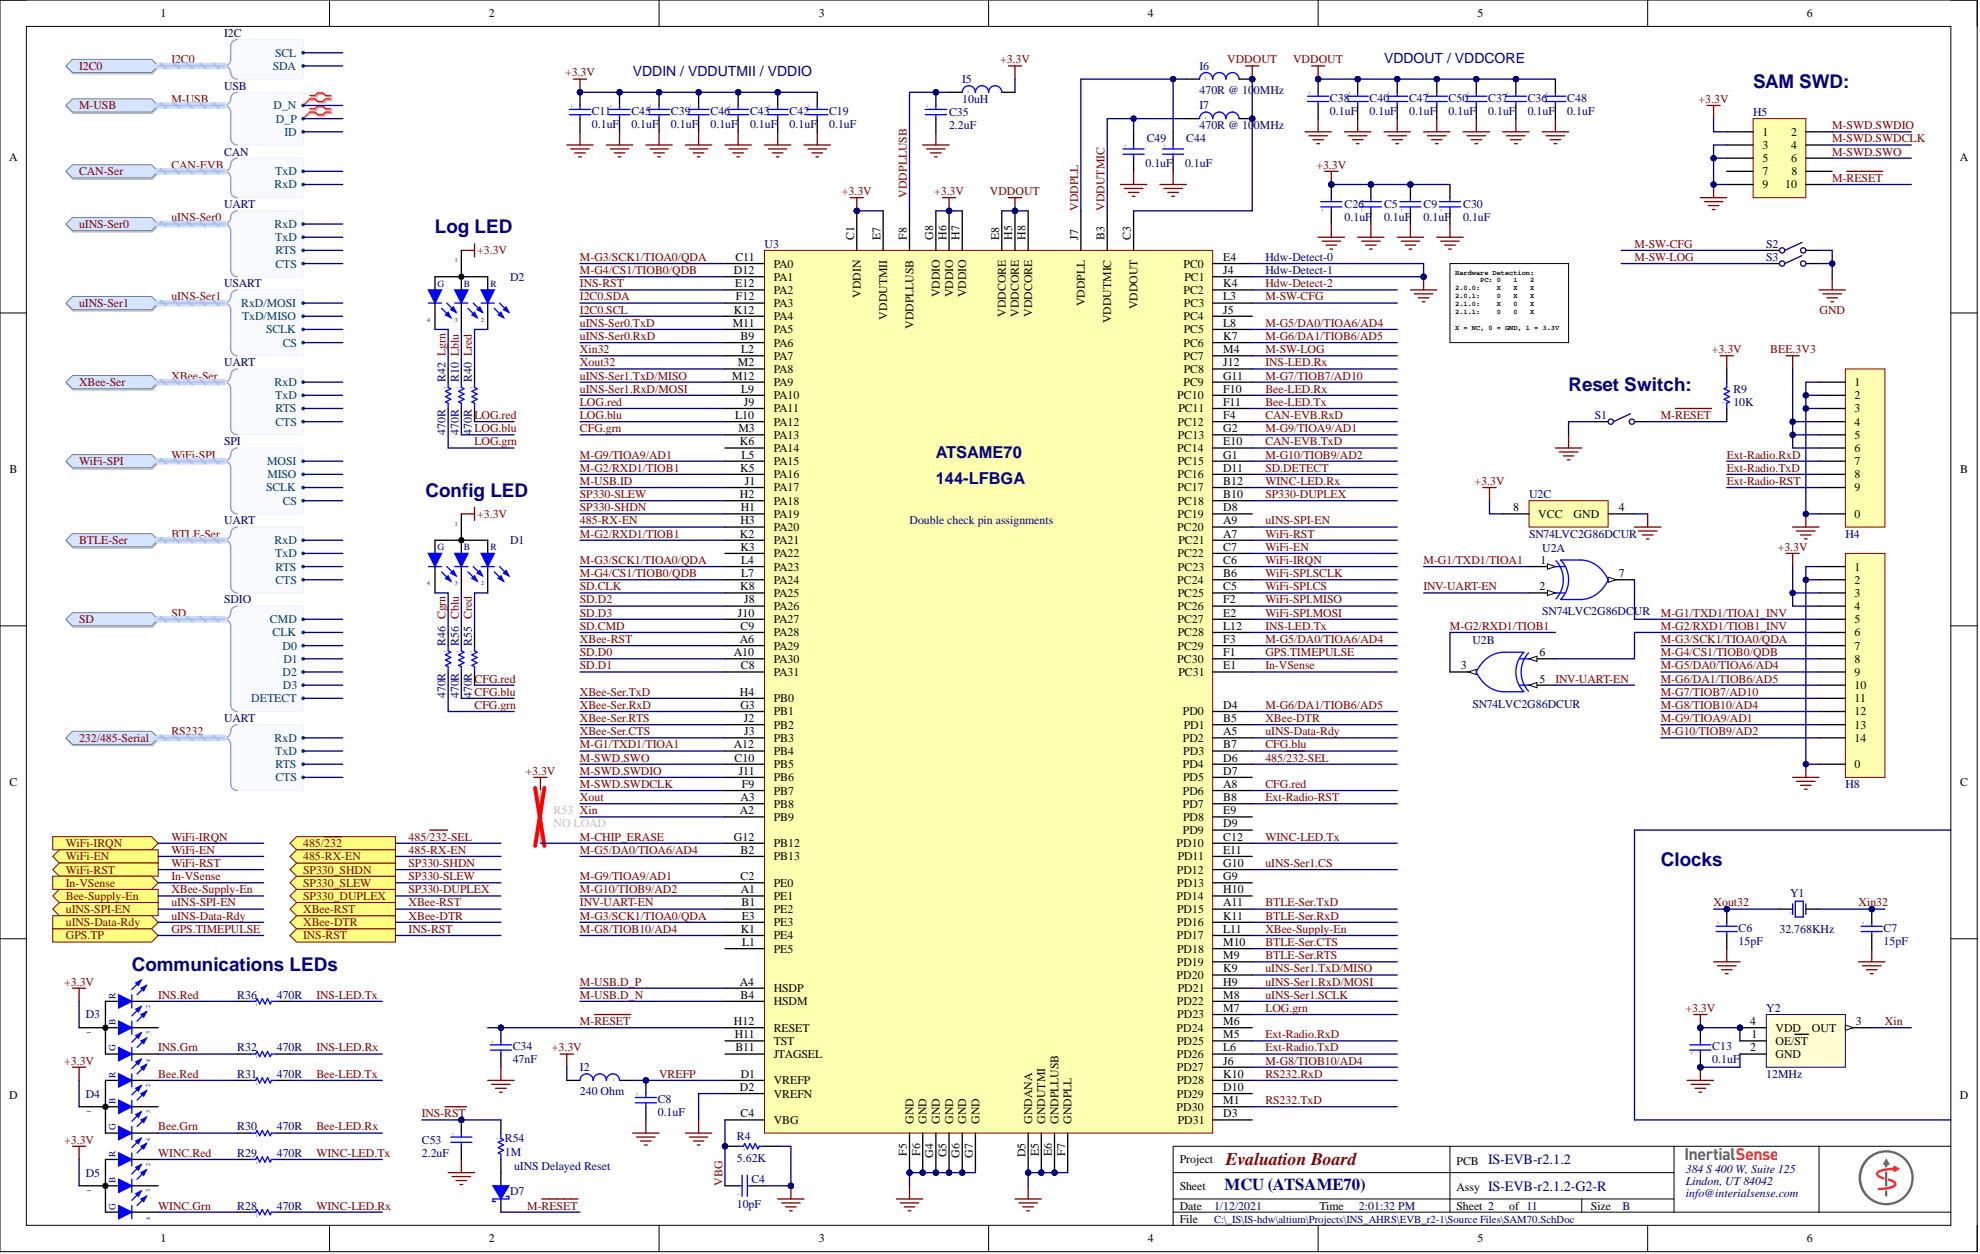
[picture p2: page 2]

GND F6 GND F5 Double check pin assignments

WiFi-RST
uINS-SPI-EN

C:\_IS\IS-hdw\altium\Projects\INS_AHRS\EVB_r2-1\Source Files\SAM70.SchDoc

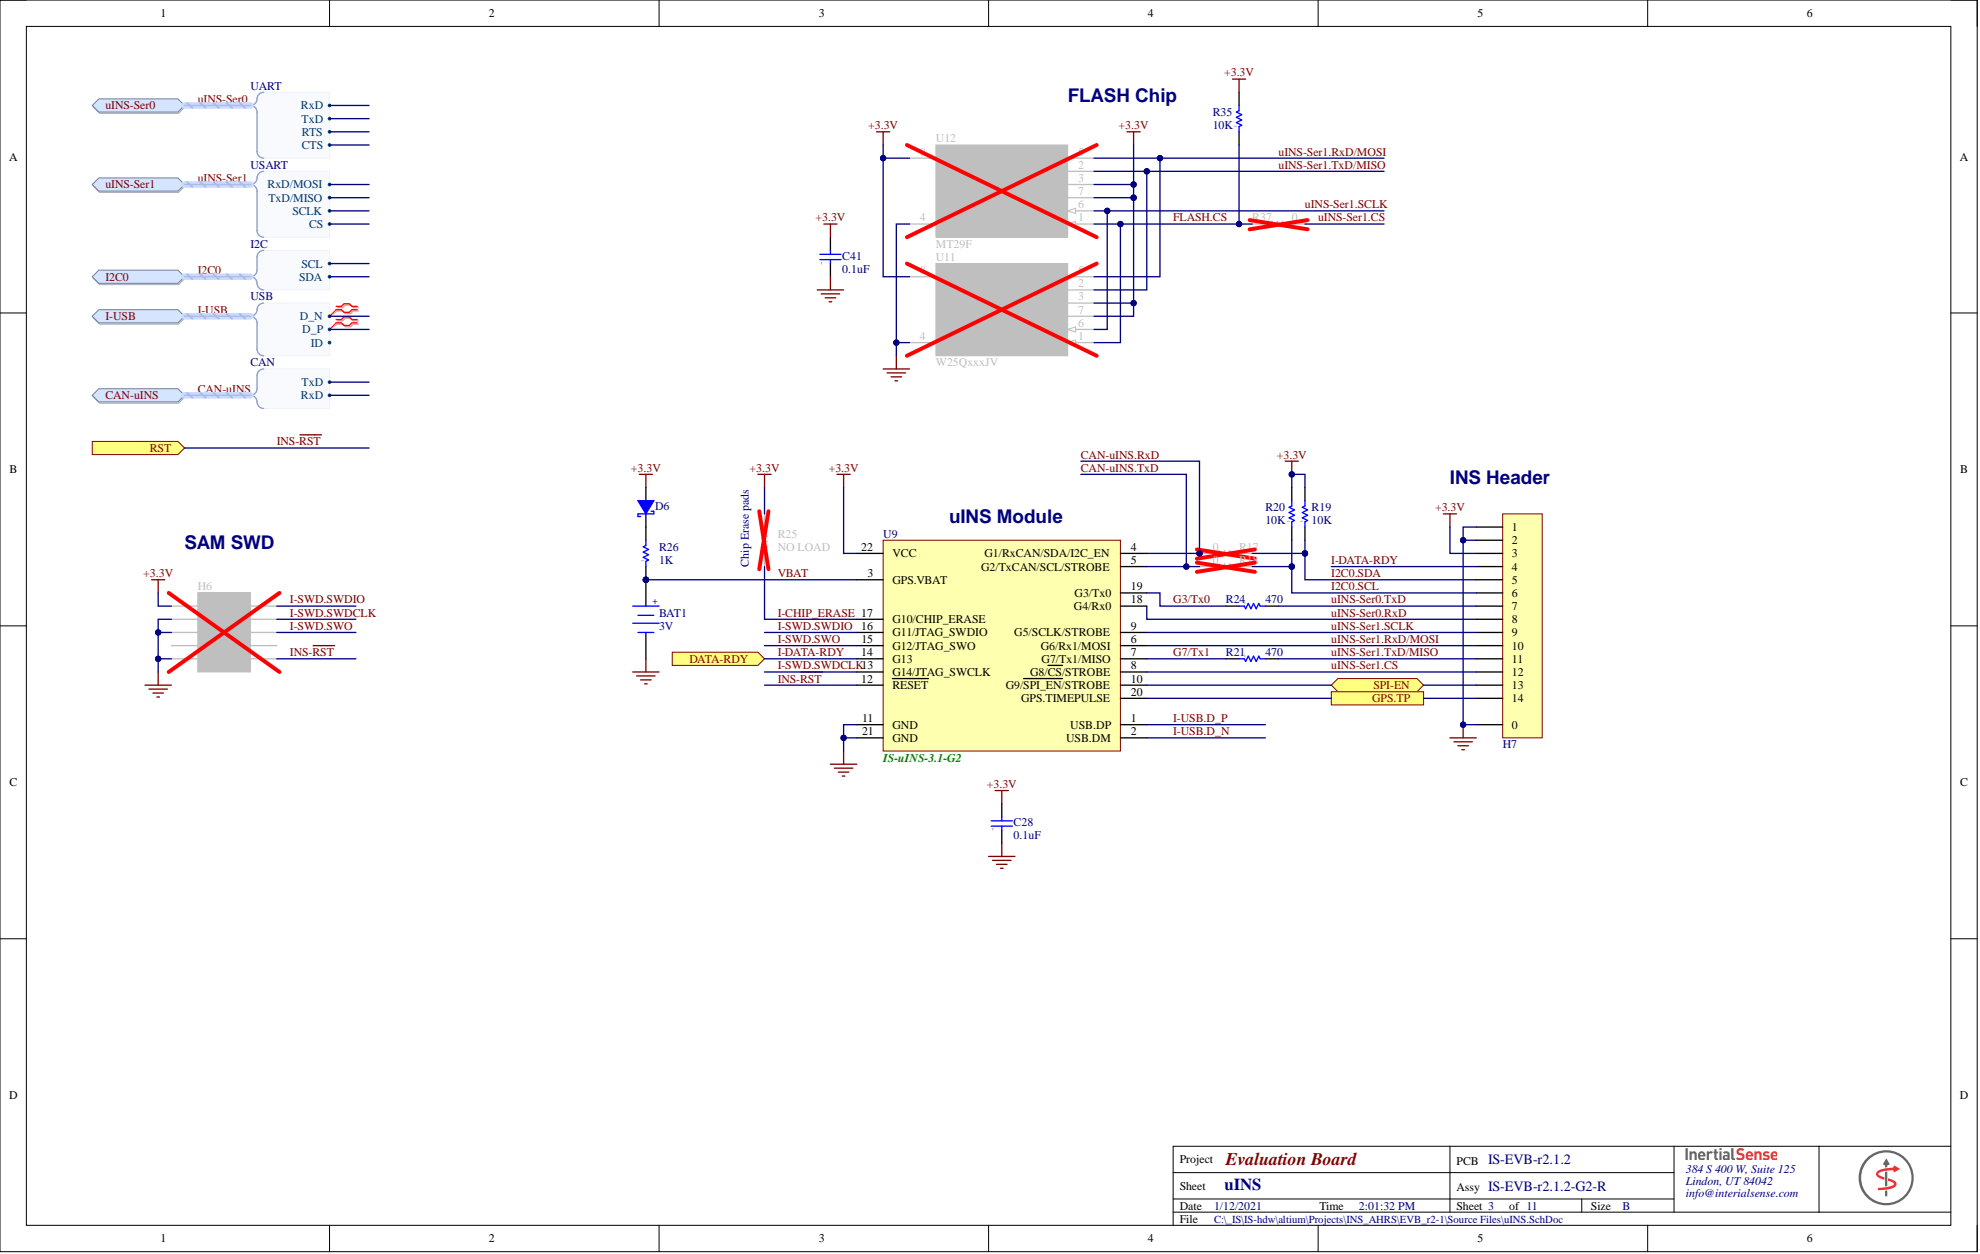
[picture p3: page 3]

C:\_IS\IS-hdw\altium\Projects\INS_AHRS\EVB_r2-1\Source Files\uINS.SchDoc

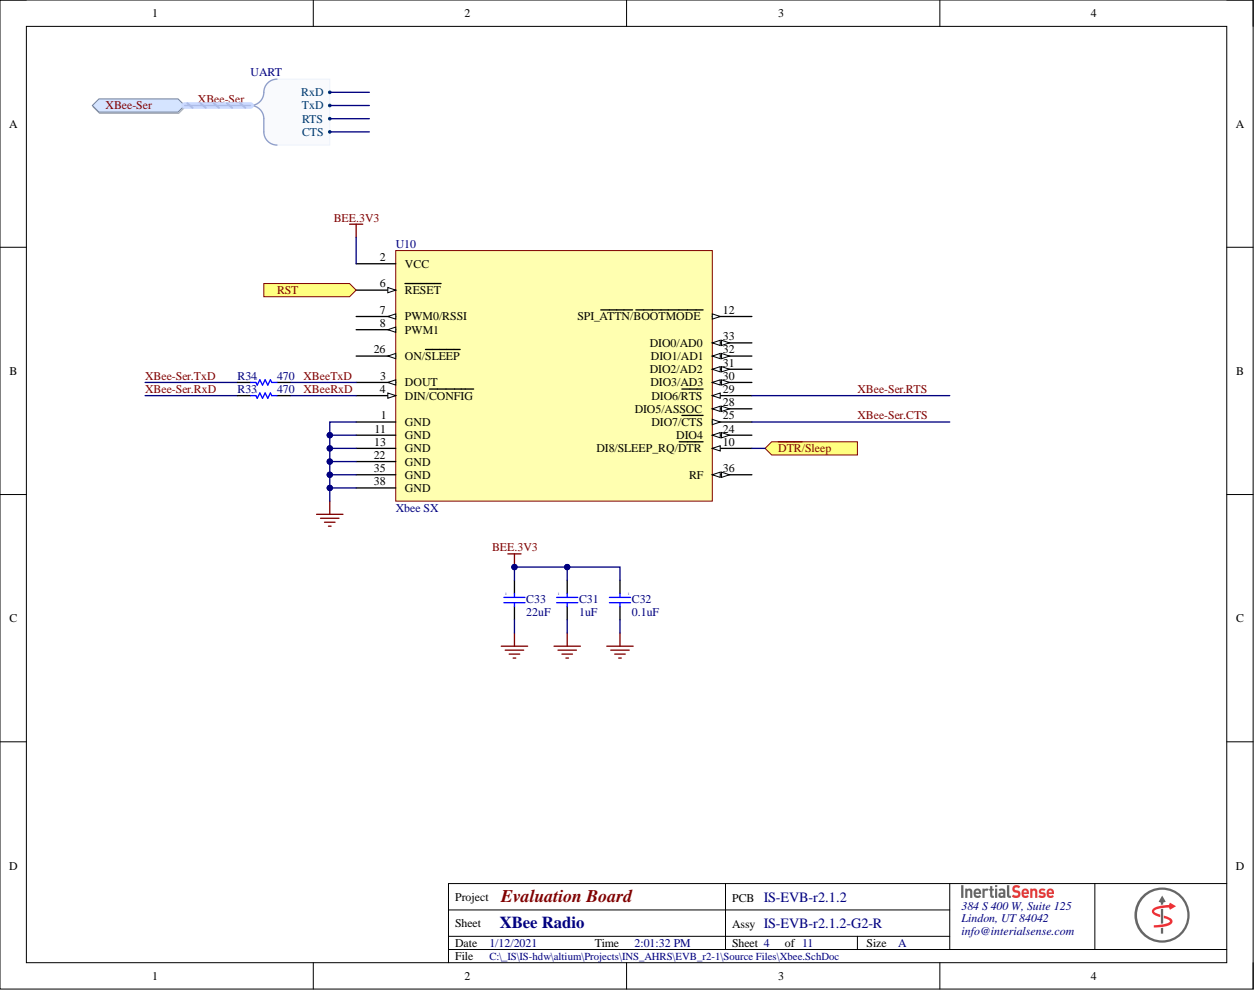
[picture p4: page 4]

C:\_IS\IS-hdw\altium\Projects\INS_AHRS\EVB_r2-1\Source Files\Xbee.SchDoc

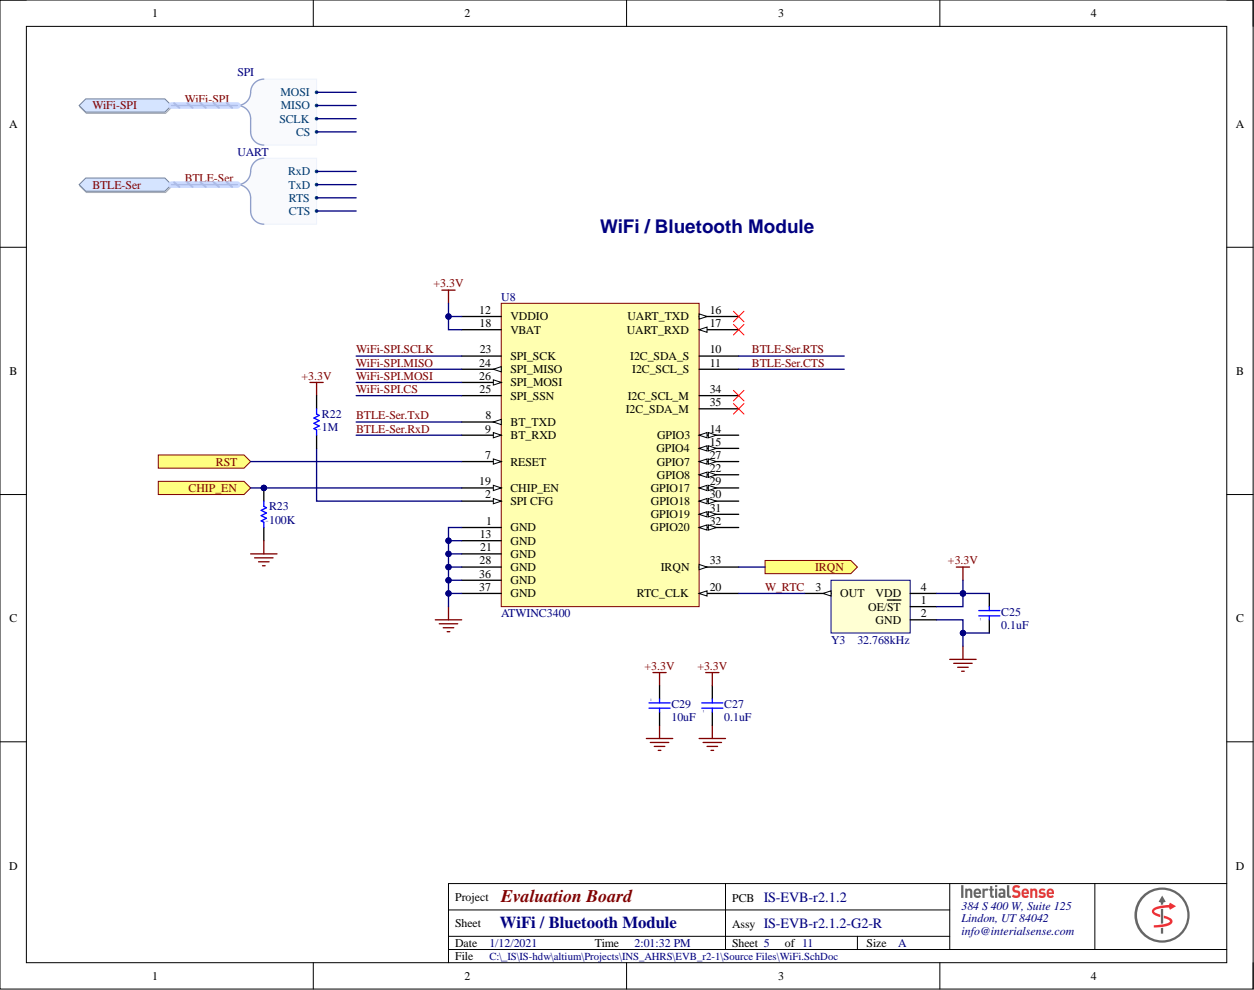
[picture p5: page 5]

C:\_IS\IS-hdw\altium\Projects\INS_AHRS\EVB_r2-1\Source Files\WiFi.SchDoc

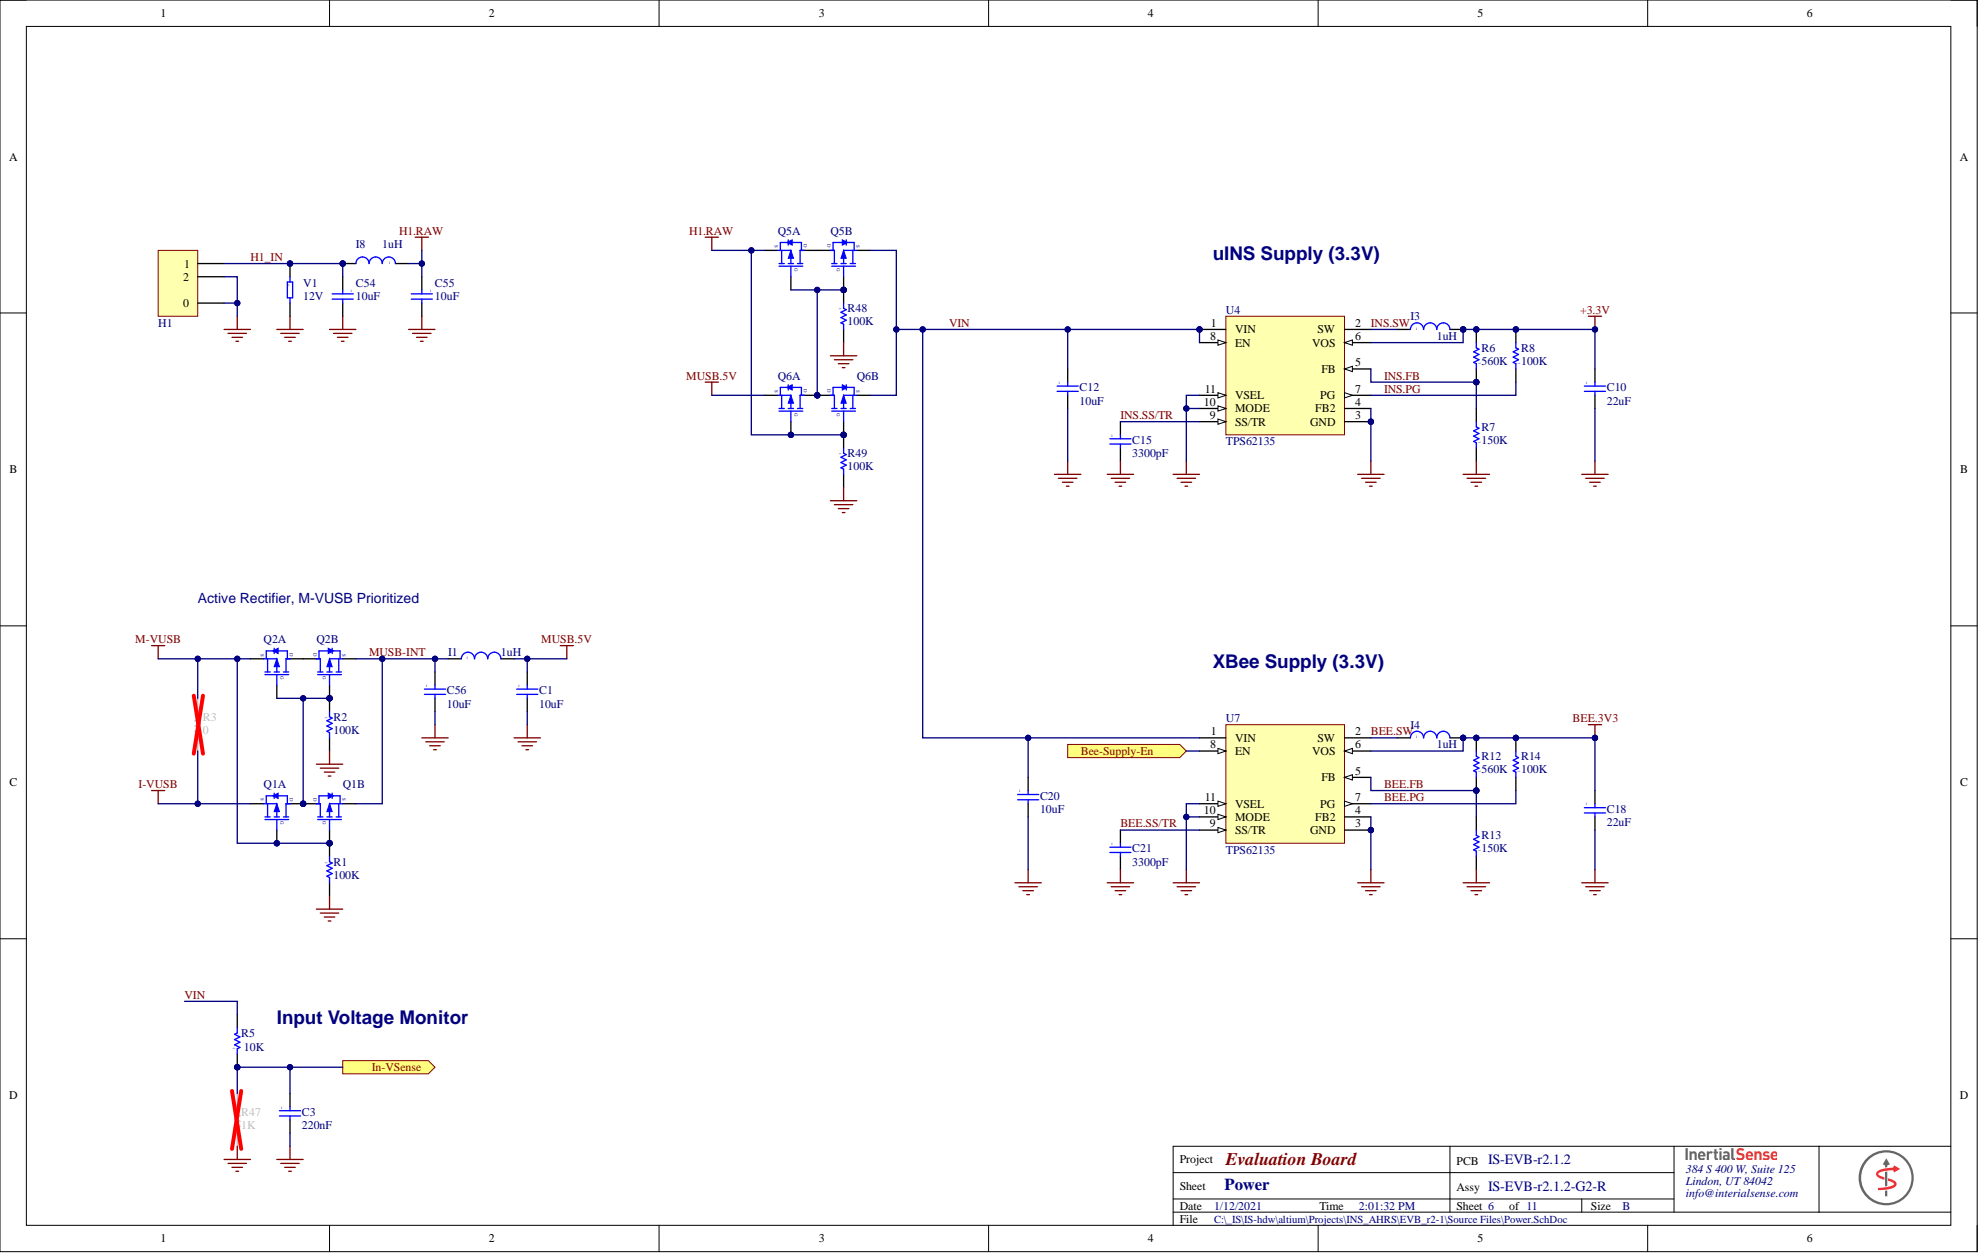
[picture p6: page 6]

Active Rectifier, M-VUSB Prioritized 10

urce Files\Power.SchDo

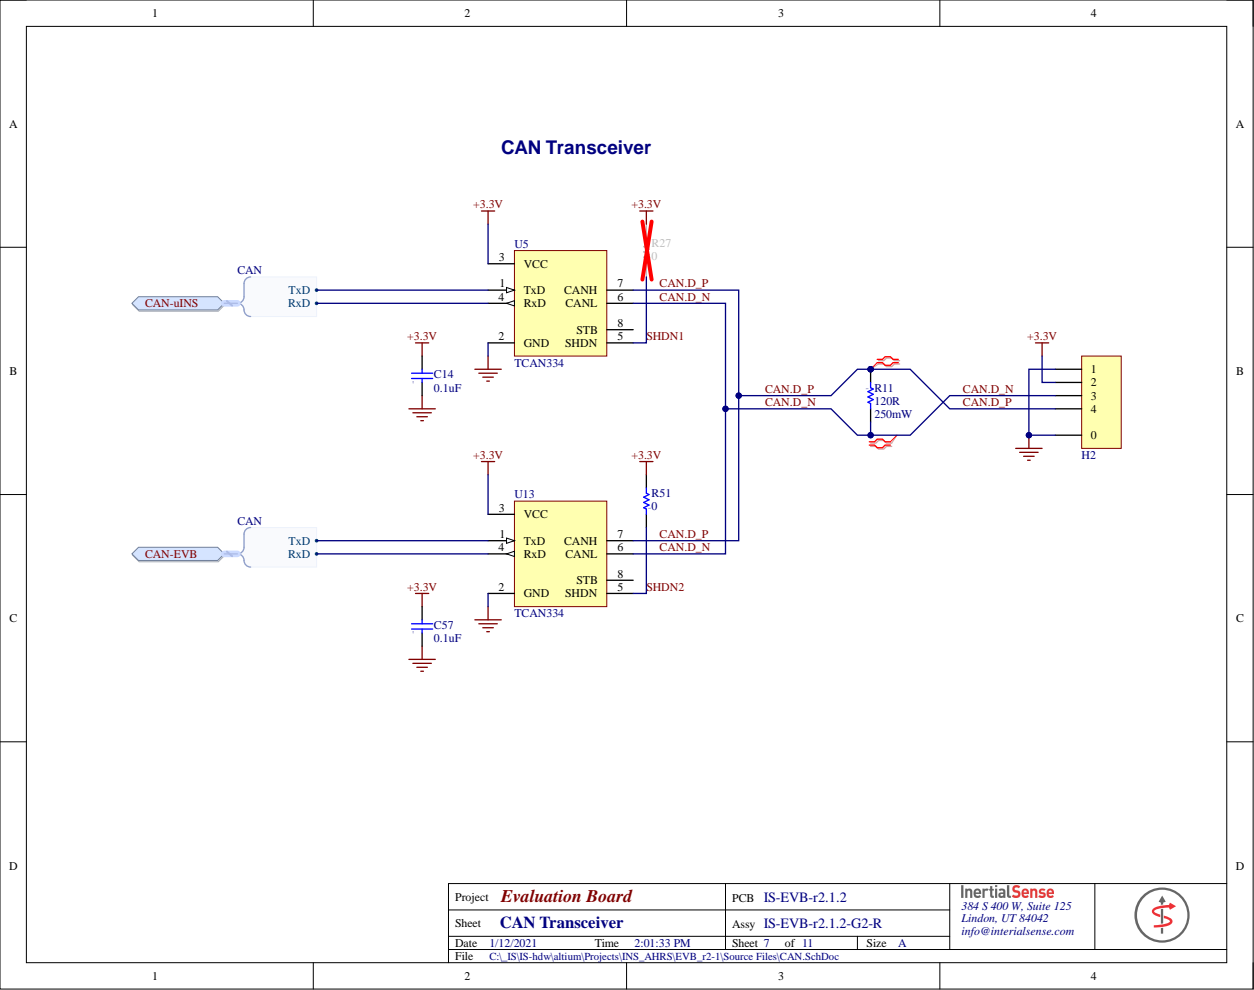
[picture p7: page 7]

urce Files\CAN.SchDo

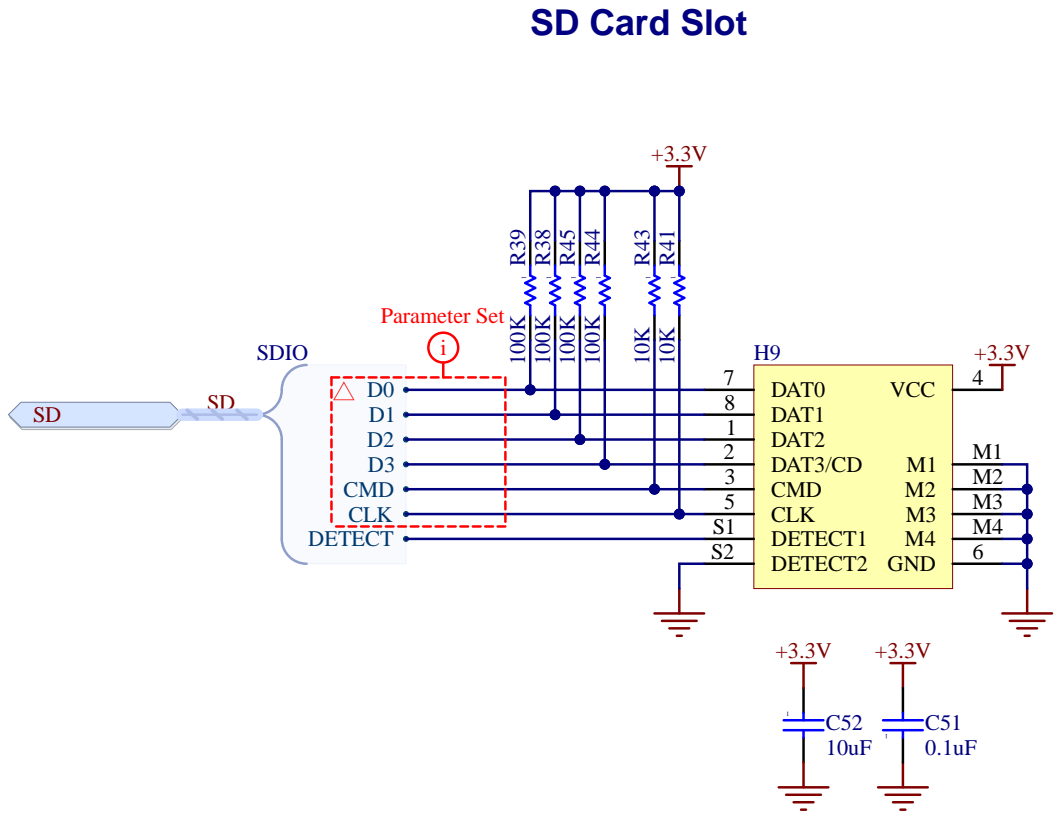
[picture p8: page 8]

C:\_IS\IS-hdw\altium\Projects\INS_AHRS\EVB_r2-1\Source Files\SD-Card.SchDoc

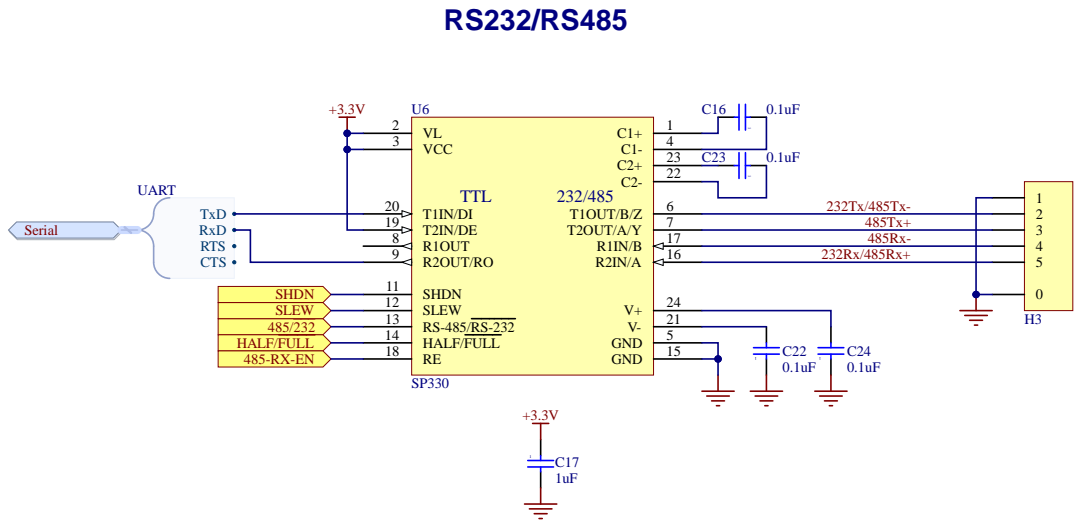
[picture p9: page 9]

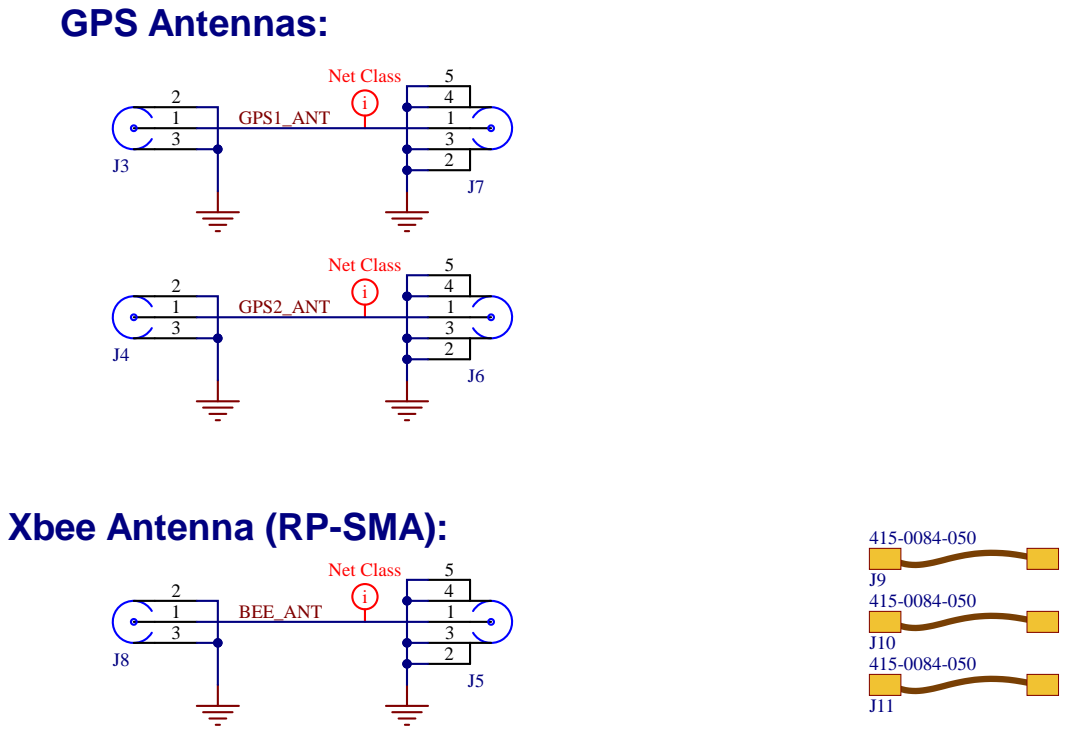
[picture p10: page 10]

Sheet 10 of
urce Files\RF.SchDo

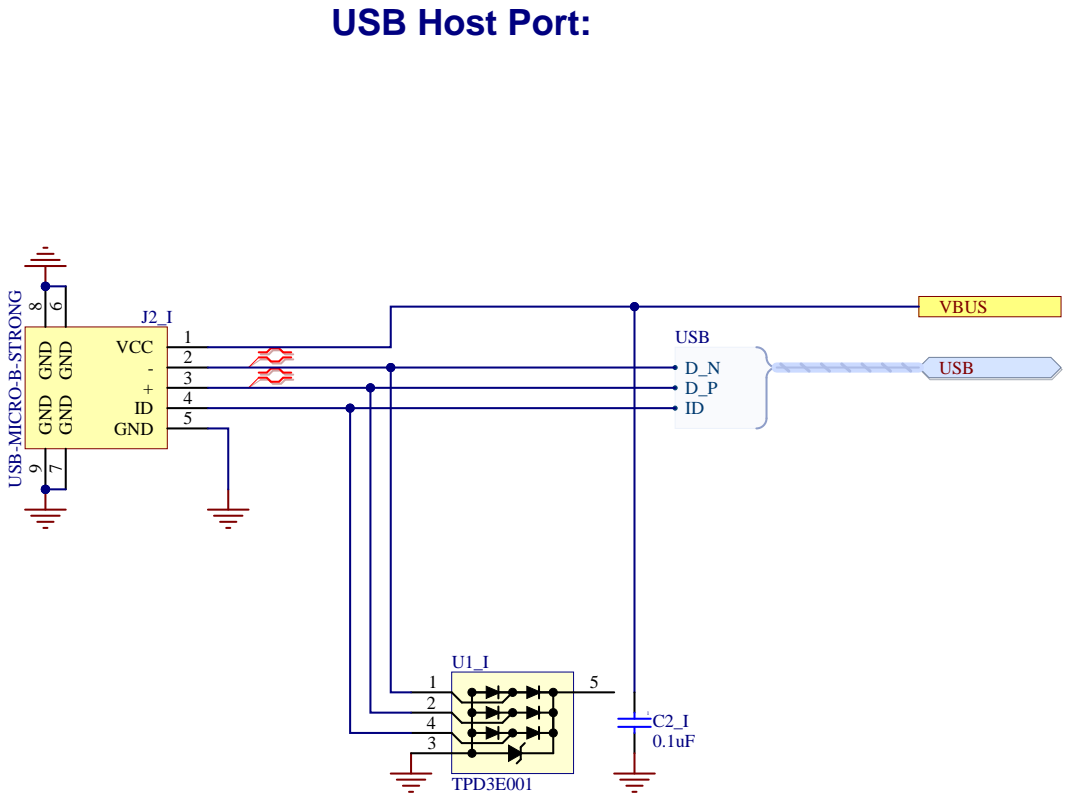
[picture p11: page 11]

urce Files\CON-USB.SchDo

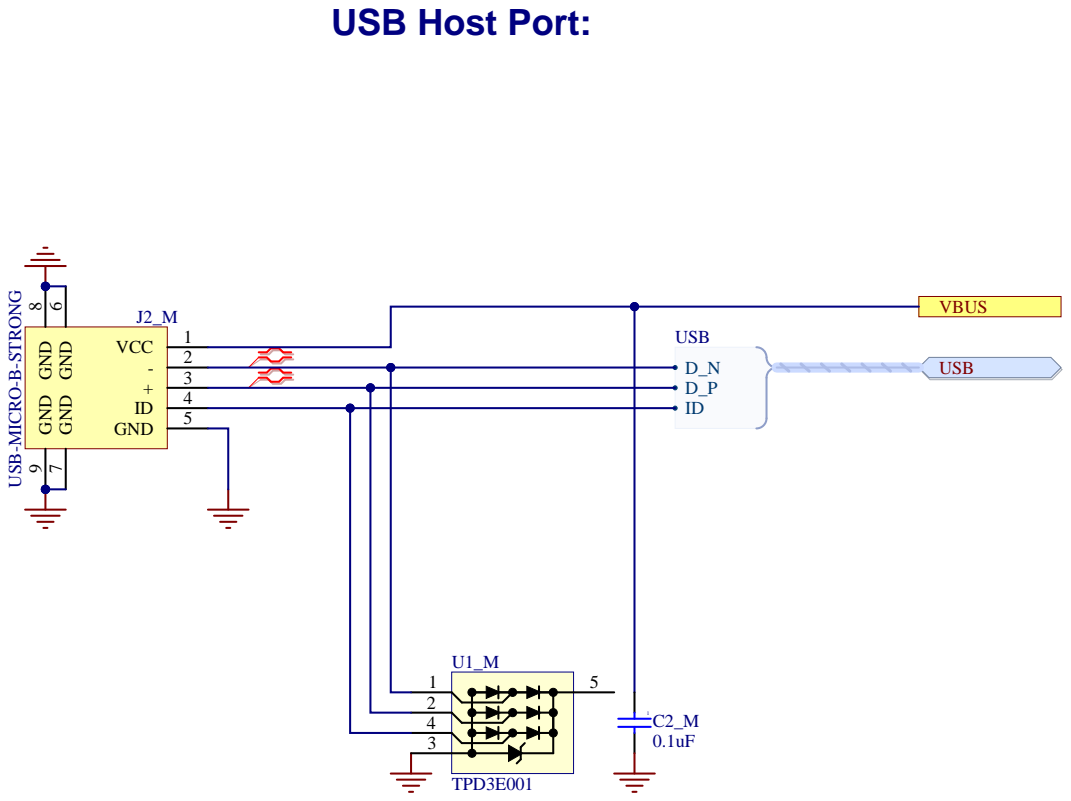
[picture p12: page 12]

urce Files\CON-USB.SchDo

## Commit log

2019-06-27 Added EVB-2 files.
    [BOM Purchase-EVB_r2-0(IS-EVB-r2.0.1-R.xlsx, CAN.SchDoc, CON-USB.SchDoc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]
2020-05-07 Added EVB-2.1.0.
    [BOM Purchase-EVB_r2-0(IS-EVB-r2.0.1-R.xlsx, BOM Purchase-EVB_r2-1(IS-EVB-r2.1.0-G2-R).xls, CAN.SchDoc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]
2020-05-07 Added missing schematic.
2021-02-12 Updated with r2.1.2
    [BOM Purchase-EVB_r2-1(IS-EVB-r2.1.0-G2-R).xls, BOM Purchase-EVB_r2-1(IS-EVB-r2.1.2-G2-R).xlsx, CAN.SchDoc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]
